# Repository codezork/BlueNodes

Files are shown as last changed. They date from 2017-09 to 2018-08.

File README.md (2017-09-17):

# BlueNodes
Bluetooth Smart Home Appliance

BlueNodes is a Smart Home system. Each BlueNode is a small box containing a Bluetooth Low Energy chip, a MOSFET switch, a current measurement sensor and a power supply. Together they establish a mesh-network of Bluetooth® devices and broadcast values to their neighbours. BlueNode devices are inserted in power supply lines to control and measure the power consumption of the endpoint. Android devices since version 4.4 with an installed BlueNodes Controller application are able to connect to the closest BlueNode and exchange information with any node in the network. Every node is reachable in the network as long as a broadcasting path exists to the addressed node. The number of nodes is nearly unlimited. A node can be mounted inside wall sockets, lamp stands, junction boxes and light switches. BlueNode devices can switch or dim loads while supplying continuous information about power consumption of each node in the network. You can start your Smart Home with just one BlueNode.

== Usage
The BlueNodes system consists of hardware, firmware and android software.

=== Prerequisites
==== Hardware
To read and modify schematics and pcb layout, you need to install gEDA (http://www.geda-project.org/) from: http://wiki.geda-project.org/geda:download. You have to copy the gEDA folder of this repo over your gEDA installation to add symbols and footprints that are added for this project. You have to add the bluenodes directory to the gEDA settings or copy footprints (*.fp) and symbols (*.sym) to an existing folder. Gerber files of the latest version and images of the pcb are included. The gerber files can directly be used to order a 4 layer pcb at a pcb manufacturer, e.g.: http://www.pcb-pool.com/.
==== Firmware
If you want to upload new versions of the firmware to the BlueNodes hardware, you either need to have a J-Link debug probe from https://www.segger.com/products/debug-probes/j-link/ or you buy a Nordic development board and solder your connection by yourself. The board and all the used chips and parts are available from Mouser Electronics http://www.mouser.de/.
To compile the firmware, use EmBitz version 1.11. You can download it here: https://www.embitz.org/.
==== Android
Get the latest version of Android Studio from https://developer.android.com/studio/index.html.
== License
Schematic and pcb layout, firmware and android software is published, as far as not under the Nordic Semiconductor ASA license (Nordic LICENSE file), under the Apache 2.0 license.

== Disclaimer
Although the author takes all possible care to ensure the correctness of published information, no warranty can be accepted regarding the correctness, accuracy, uptodateness, reliability and completeness of the content of this information. The author expressly reserves the right to change, to delete or temporarily not to publish the contents wholly or partly at any time and without giving notice. Liability claims against the author because of tangible or intangible damage arising from accessing, using or not using the published information, through misuse of the connection or as a result of technical breakdowns are excluded.

=== Warning
The hardware includes a so called "Buck Converter" which does not implement galvanic separation from the mains. Therefore care must be taken and the device should never be touched when connected to mains.
While high voltage systems can be dangerous, and if not treated with care, respect and intelligence, they can result in fatal injuring. Damaging effects which can be induced in the body by electric shock or contact with live electrical systems include:
1. Ventricular fibrillation - defined by the New Oxford American Dictionary as "(of a muscle, esp. in the heart) make a quivering movement due to uncoordinated contraction of the individual fibrils." This is a potentially fatal condition where the heart muscle quivers rather than beats, eliminating blood flow and causing death.
2. Cardiac asystole - where the heart stops beating. Combined with ventricular fibrillation this constitutes cardiac arrest.
3. Respiratory arrest.
4. Burns from arc flash and resistive heating of body tissues.
5. Radio frequency burns if radio or microwave frequencies are used.
If you are not familiar with devices connected to mains and voltages higher that 35 volts, contact a specialist before connecting a BlueNodes device to mains. The author cannot be held liabile for personal injuries or other damages resulting in the use of the published schematics.
Also, a Buck Converter can emit ERM which should always be shielded. The schamatics and the pcb layout takes care about this fact.

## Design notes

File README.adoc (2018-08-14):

= BlueNodes
Bluetooth Smart Home Appliance

BlueNodes is a Smart Home system. Each BlueNode is a small box containing a Bluetooth Low Energy chip, a MOSFET switch, a current measurement sensor and a power supply. Together they establish a mesh-network of Bluetooth® devices and broadcast values to their neighbours. BlueNode devices are inserted in power supply lines to control and measure the power consumption of the endpoint. Android devices since version 4.4 with an installed BlueNodes Controller application are able to connect to the closest BlueNode and exchange information with any node in the network. Every node is reachable in the network as long as a broadcasting path exists to the addressed node. The number of nodes is nearly unlimited. A node can be mounted inside wall sockets, lamp stands, junction boxes and light switches. BlueNode devices can switch or dim loads while supplying continuous information about power consumption of each node in the network. You can start your Smart Home with just one BlueNode.

== General
The BlueNodes system consists of hardware, firmware and android software. The firmware is based on https://github.com/NordicSemiconductor/nRF51-ble-bcast-mesh[nRF OpenMesh].
To understand the complete project read link:docs/details.adoc[Details].

== Prerequisites

=== Hardware
To read and modify schematics and pcb layout, you need to install gEDA (http://www.geda-project.org/) from: http://wiki.geda-project.org/geda:download. You have to copy the gEDA folder of this repo over your gEDA installation to add symbols and footprints that are needed for this project. You have to add the bluenodes directory to the gEDA settings or copy footprints and symbols to an existing gEDA symbol and footprint folder. 

Gerber files of the latest version and images of the pcb are in the repo. The pcb is assembled from both sides with SMD parts mounting form 0402. The gerber files can directly be used to order a 4 layer pcb at a pcb manufacturer, e.g.: http://www.pcb-pool.com/.

=== Firmware
If you want to upload new versions of the firmware to the BlueNodes hardware, you either need to have a J-Link debug probe from https://www.segger.com/products/debug-probes/j-link/ or you buy a Nordic development board and solder the connection yourself. See https://devzone.nordicsemi.com/question/80853/external-programming-using-nrf52-dk/. +
The development board and all parts needed for BlueNodes are available from Mouser Electronics http://www.mouser.de/. Order numbers for Mouser parts should be supplied in the schematics.

To compile the firmware, use EmBitz from version 1.11. You can download it here: https://www.embitz.org/.

=== Android
Get the latest version of Android Studio from https://developer.android.com/studio/index.html.

== License
Schematic and pcb layout, firmware and android software is published, as far as not under the Nordic Semiconductor ASA license (Nordic LICENSE file), under the *Apache 2.0 license*.

== Disclaimer
Although the author takes all possible care to ensure the correctness of published information, no warranty can be accepted regarding the correctness, accuracy, uptodateness, reliability and completeness of the content of this information. The author expressly reserves the right to change, to delete or temporarily not to publish the contents wholly or partly at any time and without giving notice. Liability claims against the author because of tangible or intangible damage arising from accessing, using or not using the published information, through misuse of the connection or as a result of technical breakdowns are excluded.

=== Warning!
The hardware includes a so called "Buck Converter" which does not implement galvanic separation from the mains. Therefore care must be taken and the device should never be touched when connected to mains.
While high voltage systems can be dangerous, and if not treated with care, respect and intelligence, they can result in fatal injuring. Damaging effects which can be induced in the body by electric shock or contact with live electrical systems include: +
1. Ventricular fibrillation - defined by the New Oxford American Dictionary as "(of a muscle, esp. in the heart) make a quivering movement due to uncoordinated contraction of the individual fibrils." This is a potentially fatal condition where the heart muscle quivers rather than beats, eliminating blood flow and causing death. +
2. Cardiac asystole - where the heart stops beating. Combined with ventricular fibrillation this constitutes cardiac arrest. +
3. Respiratory arrest. +
4. Burns from arc flash and resistive heating of body tissues. +
5. Radio frequency burns if radio or microwave frequencies are used. +
If you are not familiar with devices connected to mains and voltages higher that 35 volts, contact a specialist before connecting a BlueNodes device to mains. The author cannot be held liabile for personal injuries or other damages resulting in the use of the published schematics. +
Also, a Buck Converter can emit ERM which should always be shielded. The schematics and the pcb layout takes care about this fact.

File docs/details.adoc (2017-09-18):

== Features

*Simplicity*
BlueNodes are easy to install at any place in the electrical circuit of a facility. They work with every AC mains voltage from 85V up to 265V. No extra power supply is needed for the devices.

*Extensibility*
installations can easily be extended starting with a single node because new nodes integrate seamlessly into the network without programming an address. 

*Independence*
any Android driven device with Bluetooth® 4.0 capabilities can hook into the network and control loads or gain live data over power consumptions. No special hardware is required. 

*Maintainability and Sustainability*
when firmware updates become available OTA-DFU (Over the Air Device Firmware Update) transports new firmware from the Android device to all nodes.

*Security*
Nodes can detect short-circuit situations or overload and cut mains before any fuse can break. An in-built temperature sensor avoids overheating. 

*Convenience*
Android devices with a running BlueNodes Controller application, automatically log into the mesh-network as they come into range. 

== Software
=== Firmware
uses BLE protocol stack, rebroadcasting mesh network technology using the IETF RFC6206 Trickle algorithm. Each node has a unique address and embedds automatically into an existing network. Different channels and access addresses can be configured to separate networks. Electrical current is measured by the sensor and converted continuously by the A/D converter.

=== Android Software
the Java based Android software automatically connects to the closest BlueNode. Once connected, all nodes are reachable. The facility can be structured in buildings - floors - rooms - lamps or other loads. New nodes can be inserted and given a name and icon. Structural data is stored in the Android devices' Sqlite database. The power management displays accumulated consumption statistics in kWh per Minute of an hour - hour of a day - day of a month - etc. The values are permanently stored in the devices' flash memory and can be reset anytime.

== Hardware
*PCB*
assembled double side on a 4 layer PCB 37.5 x 27 mm using SMD 0402 parts.

*SOC*
NRF51x22 based on ARM® Cortex M0 32 bit processor 16 MHz clock Bluetooth® 4.0 low energy 2.4 GHz RF.

*RF*
Johanson Technology 2.4 GHz SMD ceramic antenna with impedance matched balun and band pass filter.

*Current Sensor*
Infineon TLI4970-D025T5 miniature coreless magnetic current sensor for AC and DC measurements with digital interface and fast overcurrent detection.

*Load Switch*
dual Infineon MOSFET 600V CoolMOS™ CE Power Transistor with trailing-edge phase cut control.

*Power Supply*
VIPer™06 30 kHz PWM non-isolated buck converter circuit with 1.8V and 5V LDO output. Maximum   power consumption 30mA during continuous RF communication.

*Indicators*
2 LED indicating connection and health status.

*Interface*
5 pin connector pad with Vdd, GND, GND detect, SWDIO and SWDCLK

Block diagram

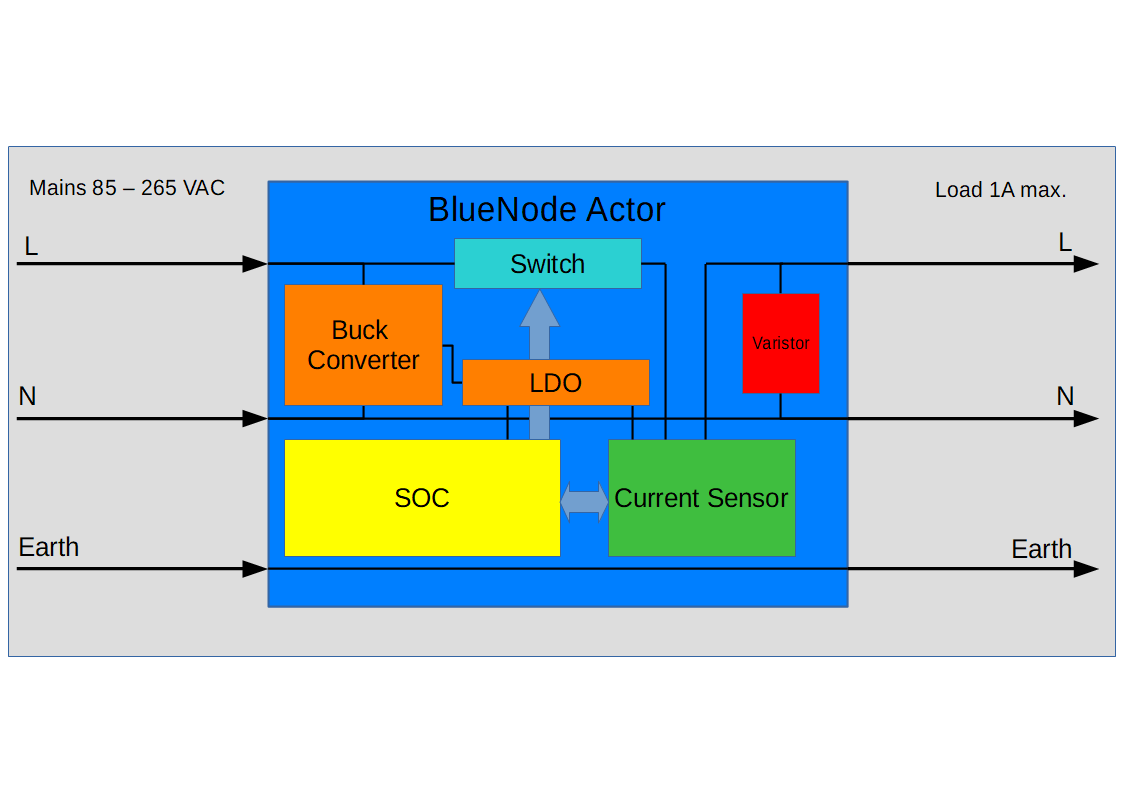
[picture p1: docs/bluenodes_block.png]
Block diagram


Schematics

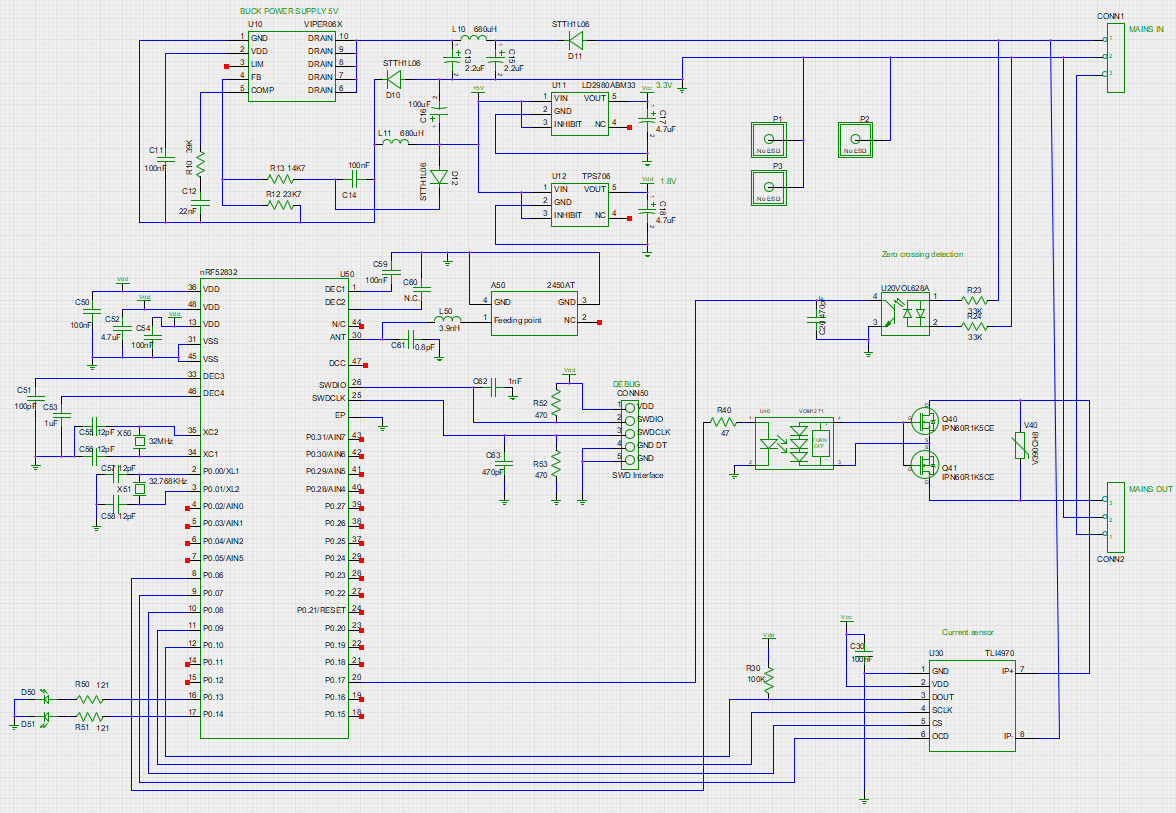
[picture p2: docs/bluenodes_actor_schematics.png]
Schematics


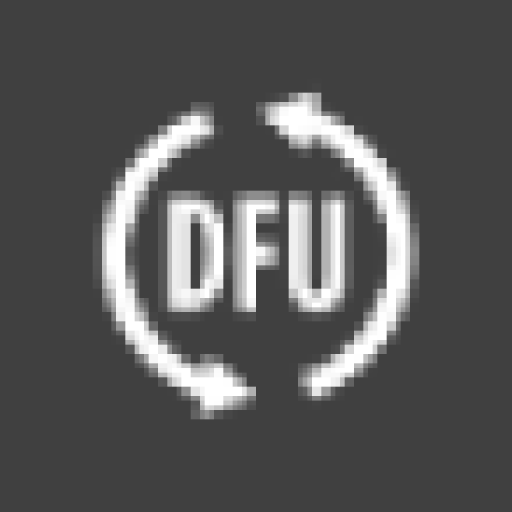
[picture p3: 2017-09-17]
mobile/bluenodes/src/main/ic_stat_notify_dfu-web.png

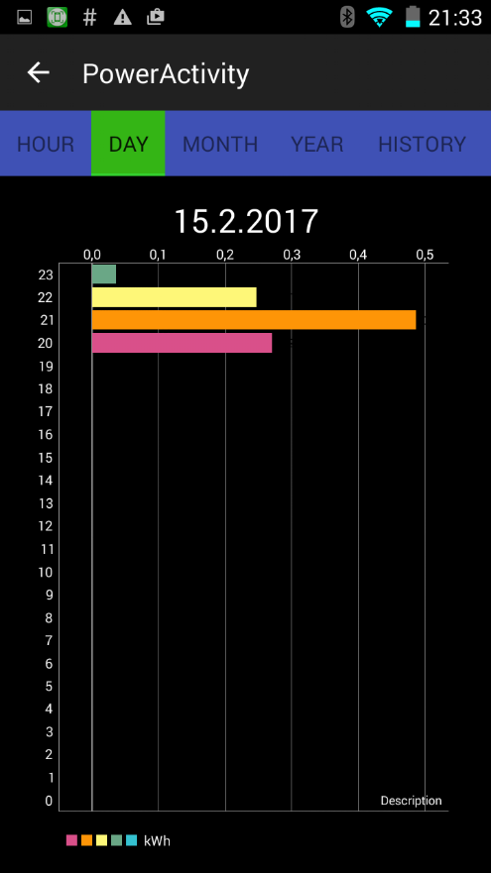
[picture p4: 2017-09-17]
screenshots/Screenshot_2017-02-15-21-33-17.png

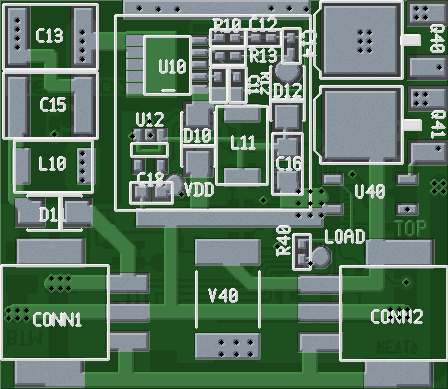
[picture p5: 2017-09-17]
pcb/bluenodes_actor52832-19-top.png

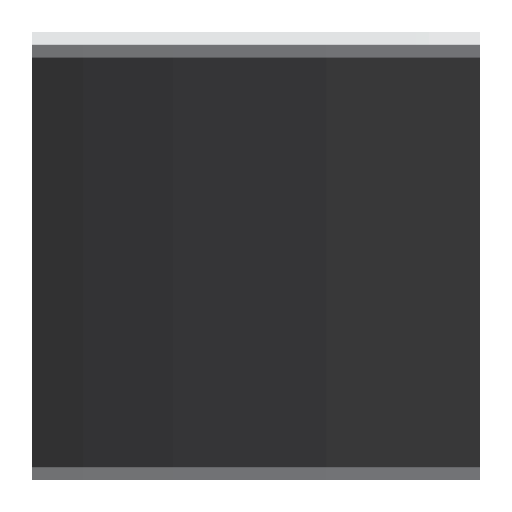
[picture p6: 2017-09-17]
mobile/bluenodes/src/main/battery-web.png

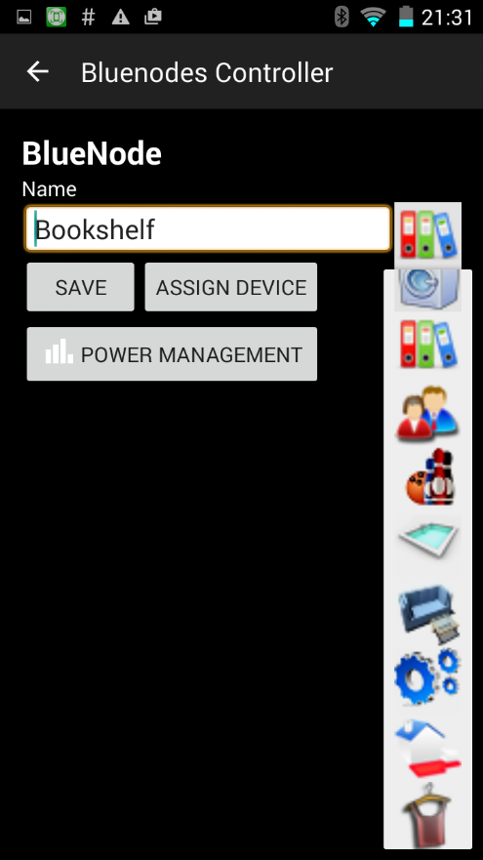
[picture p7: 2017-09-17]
screenshots/Screenshot_2017-02-15-21-31-52.png

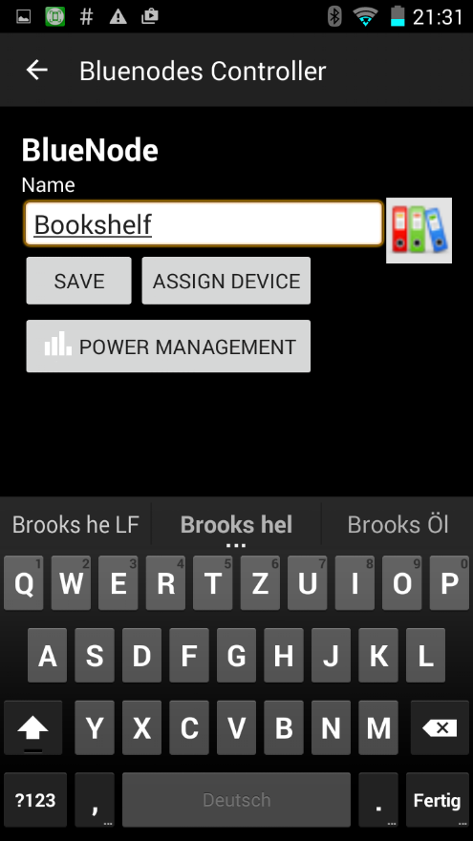
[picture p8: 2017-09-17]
screenshots/Screenshot_2017-02-15-21-31-35.png

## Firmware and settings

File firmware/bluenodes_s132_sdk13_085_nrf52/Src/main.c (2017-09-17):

/***********************************************************************************
Copyright (c) Bluenodes GmbH
All rights reserved.

Redistribution and use in source and binary forms, with or without modification,
are not permitted.
************************************************************************************/

#include "rbc_mesh.h"
#include "nrf_adv_conn.h"
#include "nrf_soc.h"
#include "softdevice_handler.h"
#include "nrf_drv_rng.h"
#include <string.h>
#include "app_button.h"
#include "app_timer.h"
#include "bas_adc.h"
#include "fstorage.h"
#include "fstorage_internal_defs.h"
#include "led_config.h"
#include "mesh.h"
#include "config.h"
#include "common.h"
#include "peripheral.h"
#include "current_cube.h"
#ifdef MESH_DFU
#include "dfu_app.h"
#endif

#include "SEGGER_RTT.h"

/** rtc timers **/
// request addresses timeout
#define REQUEST_DEVICEADDRESSES_TIMEOUT					APP_TIMER_TICKS(10)
APP_TIMER_DEF(m_request_deviceaddress_timer_id);
#define TEMPERATURE_TIMEOUT					            APP_TIMER_TICKS(1000)
APP_TIMER_DEF(m_temperature_timer_id);
// notify error timeout
APP_TIMER_DEF(m_notify_error_timer_id);

// message to host service timeout
APP_TIMER_DEF(m_message_timer_id);

/** global variables **/
static mesh_value_t                     m_message;
static volatile bool                    m_radio_active = false;
static volatile bool                    m_connected = false;
static volatile bool                    m_memory_access_in_progress = false;
// global static device adress
static ble_gap_addr_t 					m_my_addr;

/**
* @brief General error handler.
*/
static void error_loop(void) {
	while (true) {
		__WFE();
	}
}

/**@brief Callback function for asserts in the SoftDevice.
 *
 * @details This function will be called in case of an assert in the SoftDevice.
 *
 * @warning This handler is an example only and does not fit a final product. You need to analyze
 *          how your product is supposed to react in case of Assert.
 * @warning On assert from the SoftDevice, the system can only recover on reset.
 *
 * @param[in] line_num   Line number of the failing ASSERT call.
 * @param[in] file_name  File name of the failing ASSERT call.
 */
void assert_nrf_callback(uint16_t line_num, const uint8_t * p_file_name)
{
    app_error_handler(DEAD_BEEF, line_num, p_file_name);
}

void app_error_fault_handler(uint32_t id, uint32_t pc, uint32_t info) {
#ifndef DEBUG
    NVIC_SystemReset();
#else
    SEGGER_RTT_printf(0, "app_error_print():\r\n");
    SEGGER_RTT_printf(0, "Fault identifier:  0x%X\r\n", id);
    SEGGER_RTT_printf(0, "Program counter:   0x%X\r\n", pc);
    SEGGER_RTT_printf(0, "Fault information: 0x%X\r\n", info);

#ifndef DEBUG
    if(info == 0) {
        SEGGER_RTT_printf(0, "reset due to sd assert\r\n");
        NVIC_SystemReset();
    }
#endif
    switch (id)
    {
        case NRF_FAULT_ID_SDK_ASSERT:
            SEGGER_RTT_printf(0, "Line Number: %u\r\n", ((assert_info_t *)(info))->line_num);
            SEGGER_RTT_printf(0, "File Name:   %s\r\n", ((assert_info_t *)(info))->p_file_name);
            break;

        case NRF_FAULT_ID_SDK_ERROR:
            SEGGER_RTT_printf(0, "Line Number: %u\r\n",   ((error_info_t *)(info))->line_num);
            SEGGER_RTT_printf(0, "File Name:   %s\r\n",   ((error_info_t *)(info))->p_file_name);
            SEGGER_RTT_printf(0, "Error Code:  0x%X\r\n", ((error_info_t *)(info))->err_code);
            break;
    }
#endif
}

/**
* @brief Softdevice crash handler, never returns
*
* @param[in] pc Program counter at which the assert failed
* @param[in] line_num Line where the error check failed
* @param[in] p_file_name File where the error check failed
*/
void sd_assert_handler(uint32_t pc, uint16_t line_num, const uint8_t* p_file_name) {
    SEGGER_RTT_printf(0, "sd_error_print():\r\n");
    SEGGER_RTT_printf(0, "Program counter:   0x%X\r\n", pc);
    SEGGER_RTT_printf(0, "Line Number: %u\r\n", line_num);
    SEGGER_RTT_printf(0, "File Name:   %s\r\n", p_file_name);
	error_loop();
}

void HardFault_Handler(void) {
	error_loop();
}

void ble_radio_notification_evt_handler(bool radio_active) {
    m_radio_active = radio_active;
}

void ble_connect_event_handler(bool connected) {
    m_connected = connected;
    led_config(1,connected);
    if(connected) {
        SEGGER_RTT_printf(0, "CONNECTED\n");
    } else {
        SEGGER_RTT_printf(0, "DISCONNECTED\n");
    }
}

void adc_value_notification_evt_handler(float value, bool isMinute) {
    app_timer_stop(m_message_timer_id);
    float pwr = calc_watt_hour(value);
    pwr = value;
#ifdef SHOW_POWER
    if(m_connected) {
        memcpy((uint8_t*)m_message.value, (uint8_t*)&pwr, sizeof(float));
        m_message.size = sizeof(float);
        m_message.handle = MESSAGE_CHARACTERISTIC_HANDLE;
        app_timer_start(m_message_timer_id, NOTIFICATION_TIMEOUT, &m_message);
    }
#endif
    if(isMinute) {
        cube_set_power(pwr);
    }
}

/**
* @brief Softdevice event handler
*/
void sd_ble_evt_handler(ble_evt_t* p_ble_evt)
{
    rbc_mesh_ble_evt_handler(p_ble_evt);
    nrf_adv_conn_evt_handler(p_ble_evt);
#ifdef BATTERY_SERVICE
    bas_adc_on_ble_evt(p_ble_evt);
#endif
}

/**@brief Function for handling the Application's system events.
 *
 * @param[in]   sys_evt   system event.
 */
static void on_sys_evt(uint32_t sys_evt)
{
    switch (sys_evt)
    {
        case NRF_EVT_FLASH_OPERATION_SUCCESS:
        /* fall through */
        case NRF_EVT_FLASH_OPERATION_ERROR:

            if (m_memory_access_in_progress)
            {
                m_memory_access_in_progress = false;
            }
            break; // NRF_EVT_FLASH_OPERATION_SUCCESS and NRF_EVT_FLASH_OPERATION_ERROR
        default:
            // No implementation needed.
            break;
    }
}

/**@brief Function for dispatching a system event to interested modules.
 *
 * @details This function is called from the System event interrupt handler after a system
 *          event has been received.
 *
 * @param[in]   sys_evt   System stack event.
 */
static void sys_evt_dispatch(uint32_t sys_evt)
{
    rbc_mesh_sd_evt_handler(sys_evt);
    fs_sys_event_handler(sys_evt);
    on_sys_evt(sys_evt);
}

void print_data(char *type, uint8_t *address, uint8_t len)
{
#ifdef VERBOSE
    SEGGER_RTT_printf(0, "%s ", type);
    for(char i=0; i<len; i++)
        SEGGER_RTT_printf(0, "%02x", *(address+i));
    SEGGER_RTT_printf(0, "\n");
#endif
}

void send_mesh_value(uint8_t characteristic, uint8_t *in, uint8_t size, bool with_address) {
	uint32_t err_code;
	uint8_t tx_buffer[RBC_MESH_VALUE_MAX_LEN];
	memset(tx_buffer, 0, RBC_MESH_VALUE_MAX_LEN);
	uint8_t *ptr = tx_buffer;
	uint8_t max_size = RBC_MESH_VALUE_MAX_LEN;
	if(with_address) {
		memcpy(ptr, (uint8_t*)m_my_addr.addr, BLE_GAP_ADDR_LEN);
		ptr += BLE_GAP_ADDR_LEN;
		max_size -= BLE_GAP_ADDR_LEN;
	}
	if(max_size < size) {
		size = max_size;
	}
	memcpy(ptr, in, size);
	uint8_t length = with_address?BLE_GAP_ADDR_LEN+size:size;
	err_code = rbc_mesh_value_set(characteristic, tx_buffer, length);
	if (err_code != NRF_SUCCESS &&
			err_code != BLE_ERROR_INVALID_CONN_HANDLE &&
			err_code != NRF_ERROR_INVALID_STATE) {
		APP_ERROR_CHECK(err_code);
	}
}

void request_deviceaddresses_timeout_handler(void * p_context) {
	uint32_t err_code;

	app_timer_stop(m_request_deviceaddress_timer_id);
#ifdef VERBOSE
	print_data("answer address", m_my_addr.addr, BLE_GAP_ADDR_LEN);
#endif
	err_code = rbc_mesh_value_set(ANSWER_DEVICEADDRESS_CHARACTERISTIC_HANDLE, (void*)m_my_addr.addr, BLE_GAP_ADDR_LEN);
	if (err_code != NRF_SUCCESS &&
			err_code != BLE_ERROR_INVALID_CONN_HANDLE &&
			err_code != NRF_ERROR_INVALID_STATE) {
		APP_ERROR_CHECK(err_code);
	}
}

void message_timeout_handler(void * p_context) {
	mesh_value_t *val = p_context;
	send_mesh_value(val->handle, &val->value[0], val->size, true);
}

void message(mesh_value_t *message) {
	app_timer_stop(m_message_timer_id);
	memcpy(&m_message, message, sizeof(mesh_value_t));
	app_timer_start(m_message_timer_id, NOTIFICATION_TIMEOUT, &m_message);
}

void notify_error_timeout_handler(void * p_context)
{
	mesh_value_t *val = p_context;
	send_mesh_value(val->handle, &val->value[0], val->size, true);
}

void notify_error(mesh_value_t *message) {
	app_timer_stop(m_notify_error_timer_id);
	memcpy(&m_message, message, sizeof(mesh_value_t));
	app_timer_start(m_notify_error_timer_id, NOTIFICATION_TIMEOUT, &m_message);
}

void temperature_timeout_handler(void * p_context) {
#ifdef SHOW_TEMPERATURE
    int32_t temp;
    if(m_connected && sd_temp_get(&temp) == NRF_SUCCESS) {
        float value = ((float)temp/4);
        send_mesh_value(MESSAGE_CHARACTERISTIC_HANDLE, (uint8_t*)&value, sizeof(float), true);
    }
#endif
}

/**
* @brief RBC_MESH framework event handler. Defined in rbc_mesh.h. Handles
*   events coming from the mesh.
*
* @param[in] evt RBC event propagated from framework
*/
void rbc_mesh_event_handler(rbc_mesh_event_t* evt) {
	uint8_t brightness;
#ifdef CUBE_STORAGE
	storage_event_handler(evt);
#endif
	switch (evt->type) {
	case RBC_MESH_EVENT_TYPE_TX:
		break;
	case RBC_MESH_EVENT_TYPE_CONFLICTING_VAL:
	case RBC_MESH_EVENT_TYPE_NEW_VAL:
	case RBC_MESH_EVENT_TYPE_UPDATE_VAL:
		switch (evt->params.rx.value_handle) {
		case BRIGHTNESS_CHARACTERISTIC_HANDLE:
			if(memcmp(evt->params.rx.p_data, m_my_addr.addr, BLE_GAP_ADDR_LEN) == 0) {
				memcpy(&brightness, evt->params.rx.p_data+BLE_GAP_ADDR_LEN, sizeof(brightness));
				set_brightness_soft(brightness);
			}
			break;
		case REQUEST_DEVICEADDRESS_CHARACTERISTIC_HANDLE:
#ifdef VERBOSE
			SEGGER_RTT_printf(0, "request device addresses type:%d\n", evt->type);
#endif
			app_timer_stop(m_request_deviceaddress_timer_id);
			uint8_t rnd_delay;
			nrf_drv_rng_rand(&rnd_delay, 1);
			app_timer_start(m_request_deviceaddress_timer_id, rnd_delay*REQUEST_DEVICEADDRESSES_TIMEOUT, NULL);
			break;
		case REQUEST_BRIGHTNESS_CHARACTERISTIC_HANDLE:
			if(memcmp(evt->params.rx.p_data, m_my_addr.addr, BLE_GAP_ADDR_LEN) == 0) {
#ifdef VERBOSE
				print_data("request brightness for", evt->params.rx.p_data, BLE_GAP_ADDR_LEN);
#endif
				request_brightness();
			}
			break;
		default:
			break;
		}
		break;
	case RBC_MESH_EVENT_TYPE_INITIALIZED:
//		/* init BLE gateway softdevice application: */
//		nrf_adv_conn_init();
        break;
#ifdef MESH_DFU
    case RBC_MESH_EVENT_TYPE_DFU_BANK_AVAILABLE:
        dfu_bank_flash(evt->params.dfu.bank.dfu_type);
        break;

    case RBC_MESH_EVENT_TYPE_DFU_NEW_FW_AVAILABLE:
        dfu_request(evt->params.dfu.new_fw.dfu_type,
            &evt->params.dfu.new_fw.new_fwid,
            (uint32_t*) 0x24000);
        break;

    case RBC_MESH_EVENT_TYPE_DFU_RELAY_REQ:
        dfu_relay(evt->params.dfu.relay_req.dfu_type,
            &evt->params.dfu.relay_req.fwid);
        break;

    case RBC_MESH_EVENT_TYPE_DFU_START:
    case RBC_MESH_EVENT_TYPE_DFU_END:
        break;
    case RBC_MESH_EVENT_TYPE_DFU_SOURCE_REQ:
        break;
#endif
	}
}

/**@brief Function for the Timer initialization.
 *
 * @details Initializes the timer module.
 */
static void timers_init(void)
{
    // Initialize timer module, making it use the scheduler
    app_timer_init();

    // create request addresses timer
    APP_ERROR_CHECK(app_timer_create(&m_request_deviceaddress_timer_id,
                                APP_TIMER_MODE_SINGLE_SHOT,
                                request_deviceaddresses_timeout_handler));
    // create message timer
    APP_ERROR_CHECK(app_timer_create(&m_message_timer_id,
                                APP_TIMER_MODE_SINGLE_SHOT,
                                message_timeout_handler));
    // create notify error timer
    APP_ERROR_CHECK(app_timer_create(&m_notify_error_timer_id,
                                APP_TIMER_MODE_SINGLE_SHOT,
                                notify_error_timeout_handler));
    // create temperature timer
    APP_ERROR_CHECK(app_timer_create(&m_temperature_timer_id,
                                APP_TIMER_MODE_REPEATED,
                                temperature_timeout_handler));
}

#ifdef BOARD_PCA10028
static void button_event_handler(uint8_t pin_no, uint8_t button_action)
{
    static uint8_t button_state = 0;
    if(button_action)
    {
        button_state |= (1<<(pin_no-17));
    }
    else
    {
        button_state &= ~(1<<(pin_no-17));
    }
#ifdef VERBOSE
    SEGGER_RTT_printf(0, "BUTTON %d state %d\n",pin_no, button_state );
#endif
	send_mesh_value(BUTTON_CHARACTERISTIC_HANDLE, &button_state, sizeof(button_state), true);
}
#endif

/**@brief Function for initializing the button handler module.
 */
static void buttons_init(void)
{
    // Note: Array must be static because a pointer to it will be saved in the Button handler
    //       module.file
#ifdef BOARD_PCA10028
    uint32_t err_code;
    static app_button_cfg_t buttons[] =
    {
        {BSP_BUTTON_0, false, BUTTON_PULL, button_event_handler},
        {BSP_BUTTON_1, false, BUTTON_PULL, button_event_handler},
        {BSP_BUTTON_2, false, BUTTON_PULL, button_event_handler},
        {BSP_BUTTON_3, false, BUTTON_PULL, button_event_handler}
    };
    err_code = app_button_init(buttons, sizeof(buttons) / sizeof(buttons[0]), BUTTON_DETECTION_DELAY);
    APP_ERROR_CHECK(err_code);
#endif
}

/** @brief main function */
int main(void)
{
#ifdef VERBOSE
#ifdef BOARD_PCA10028
    SEGGER_RTT_WriteString(0, "board 10028\n");
#endif
#ifdef BOARD_PCA10031
    SEGGER_RTT_WriteString(0, "board 10031\n");
#endif
#ifdef BOARD_BLUENODES
    SEGGER_RTT_WriteString(0, "board bluenodes\n");
#endif
#endif
    /* Enable Softdevice (including sd_ble before framework) */
	nrf_clock_lf_cfg_t clock_lf_cfg = MESH_CLOCK_SOURCE;
	// Initialize the SoftDevice handler module.
	SOFTDEVICE_HANDLER_INIT(&clock_lf_cfg, NULL);
    softdevice_ble_evt_handler_set(sd_ble_evt_handler);
	softdevice_sys_evt_handler_set(sys_evt_dispatch);

	gpio_init();
    timers_init();
    buttons_init();
	APP_ERROR_CHECK(peripheral_init(adc_value_notification_evt_handler));
//    scheduler_init();
    nrf_drv_rng_init(NULL);
#ifndef NO_BLE
    /* Init the rbc_mesh */
    rbc_mesh_init_params_t init_params;

    init_params.access_addr         = MESH_ACCESS_ADDR;
    init_params.interval_min_ms     = MESH_INTERVAL_MIN_MS;
    init_params.channel             = MESH_CHANNEL;
	init_params.lfclksrc            = clock_lf_cfg;
	init_params.tx_power            = RBC_MESH_TXPOWER_0dBm;

	APP_ERROR_CHECK(rbc_mesh_init(init_params));
#endif
    sd_ble_gap_addr_get(&m_my_addr);

#ifndef NO_BLE
	APP_ERROR_CHECK(rbc_mesh_value_enable(BRIGHTNESS_CHARACTERISTIC_HANDLE));
	APP_ERROR_CHECK(rbc_mesh_value_enable(BUTTON_CHARACTERISTIC_HANDLE));
	APP_ERROR_CHECK(rbc_mesh_value_enable(REQUEST_BRIGHTNESS_CHARACTERISTIC_HANDLE));
	APP_ERROR_CHECK(rbc_mesh_value_enable(REQUEST_DEVICEADDRESS_CHARACTERISTIC_HANDLE));
	APP_ERROR_CHECK(rbc_mesh_value_enable(ANSWER_BRIGHTNESS_CHARACTERISTIC_HANDLE));
	APP_ERROR_CHECK(rbc_mesh_value_enable(ANSWER_DEVICEADDRESS_CHARACTERISTIC_HANDLE));
	APP_ERROR_CHECK(rbc_mesh_value_enable(NOTIFY_DEVICE_ERROR_CHARACTERISTIC_HANDLE));
	APP_ERROR_CHECK(rbc_mesh_value_enable(SET_TIME_CHARACTERISTIC_HANDLE));
	APP_ERROR_CHECK(rbc_mesh_value_enable(CLEAR_STORAGE_CHARACTERISTIC_HANDLE));
	APP_ERROR_CHECK(rbc_mesh_value_enable(REQUEST_STORAGE_CHARACTERISTIC_HANDLE));
	APP_ERROR_CHECK(rbc_mesh_value_enable(ANSWER_STORAGE_CHARACTERISTIC_HANDLE));
	APP_ERROR_CHECK(rbc_mesh_value_enable(MESSAGE_CHARACTERISTIC_HANDLE));
#endif

#ifdef BOARD_PCA10028
    APP_ERROR_CHECK(app_button_enable());
#endif
#ifdef CUBE_STORAGE
    APP_ERROR_CHECK(cube_init(&m_my_addr));
#endif

#ifndef NO_BLE
	/* init BLE gateway softdevice application: */
	nrf_adv_conn_init(NODE_NAME, ble_connect_event_handler);
#ifdef BATTERY_SERVICE
    bas_init();
#endif
#ifdef SHOW_TEMPERATURE
    app_timer_start(m_temperature_timer_id, TEMPERATURE_TIMEOUT, NULL);
#endif
#endif
#ifdef VERBOSE
	SEGGER_RTT_WriteString(0, "init done\n");
#endif
	led_test();
	load_test();

    rbc_mesh_event_t evt;
    /* sleep */
    while (true)
    {
        sd_app_evt_wait();
#ifndef TEST_DEBUG
		if (rbc_mesh_event_get(&evt) == NRF_SUCCESS) {
			rbc_mesh_event_handler(&evt);
			rbc_mesh_event_release(&evt);
		}
#endif
#ifdef CUBE_STORAGE
        cube_store();
#endif
    }
}

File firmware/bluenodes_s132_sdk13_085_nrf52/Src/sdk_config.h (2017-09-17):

/**
 * Copyright (c) 2017 - 2017, Nordic Semiconductor ASA
 *
 * All rights reserved.
 *
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
 * 3. Neither the name of Nordic Semiconductor ASA nor the names of its
 *    contributors may be used to endorse or promote products derived from this
 *    software without specific prior written permission.
 *
 * 4. This software, with or without modification, must only be used with a
 *    Nordic Semiconductor ASA integrated circuit.
 *
 * 5. Any software provided in binary form under this license must not be reverse
 *    engineered, decompiled, modified and/or disassembled.
 *
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
 */

#ifndef SDK_CONFIG_H
#define SDK_CONFIG_H
// <<< Use Configuration Wizard in Context Menu >>>\n
#ifdef USE_APP_CONFIG
#include "app_config.h"
#endif

// <h> nRF_ANT
//==========================================================
// <e> ANTFS_ENABLED - ant_fs - ANT File Share module.
//==========================================================
#ifndef ANTFS_ENABLED
#define ANTFS_ENABLED 0
#endif
#if  ANTFS_ENABLED
// <o> ANTFS_CONFIG_NETWORK_NUMBER - ANT-FS network number.
#ifndef ANTFS_CONFIG_NETWORK_NUMBER
#define ANTFS_CONFIG_NETWORK_NUMBER 0
#endif

// <o> ANTFS_CONFIG_CHANNEL_NUMBER - ANT-FS channel number.
#ifndef ANTFS_CONFIG_CHANNEL_NUMBER
#define ANTFS_CONFIG_CHANNEL_NUMBER 0
#endif

// <o> ANTFS_CONFIG_PAIRING_TIMEOUT - Pairing timeout - how long the UI will wait for a response to a pairing request before switching to the link layer, in seconds.
#ifndef ANTFS_CONFIG_PAIRING_TIMEOUT
#define ANTFS_CONFIG_PAIRING_TIMEOUT 120
#endif

// <o> ANTFS_CONFIG_LINK_COMMAND_TIMEOUT - Command timeout - how long the client will wait without receiving any commands before switching to the link layer, in seconds.
#ifndef ANTFS_CONFIG_LINK_COMMAND_TIMEOUT
#define ANTFS_CONFIG_LINK_COMMAND_TIMEOUT 10
#endif

// <o> ANTFS_CONFIG_TRANS_TYPE - ANT-FS Transmission Type.
#ifndef ANTFS_CONFIG_TRANS_TYPE
#define ANTFS_CONFIG_TRANS_TYPE 10
#endif

// <o> ANTFS_CONFIG_DEVICE_TYPE - ANT device type for channel configuration.
#ifndef ANTFS_CONFIG_DEVICE_TYPE
#define ANTFS_CONFIG_DEVICE_TYPE 1
#endif

// <o> ANTFS_CONFIG_BEACON_STATUS_PERIOD  - ANT-FS Beacon Message Period.

// <0=> 0.5 Hz
// <1=> 1 Hz
// <2=> 2 Hz
// <3=> 4 Hz
// <4=> 8 Hz

#ifndef ANTFS_CONFIG_BEACON_STATUS_PERIOD
#define ANTFS_CONFIG_BEACON_STATUS_PERIOD 3
#endif

// <o> ANTFS_CONFIG_TRANSMIT_POWER  - ANT Transmit Power.

// <0=> Lowest ANT Tx power level setting. (-20dBm)
// <1=> ANT Tx power > Lvl 0. (-12dBm)
// <2=> ANT Tx power > Lvl 1. (-4dBm)
// <3=> ANT Tx power > Lvl 2. Default tx power level. (0dBm)
// <4=> ANT Tx power > Lvl 3. (+4dBm)
// <128=> Custom tx power selection

#ifndef ANTFS_CONFIG_TRANSMIT_POWER
#define ANTFS_CONFIG_TRANSMIT_POWER 3
#endif

// <o> ANTFS_CONFIG_CUSTOM_TRANSMIT_POWER - ANT Custom Transmit Power.
#ifndef ANTFS_CONFIG_CUSTOM_TRANSMIT_POWER
#define ANTFS_CONFIG_CUSTOM_TRANSMIT_POWER 0
#endif

// <q> ANTFS_CONFIG_AUTH_TYPE_PAIRING_ENABLED  - Use pairing and key exchange authentication.


#ifndef ANTFS_CONFIG_AUTH_TYPE_PAIRING_ENABLED
#define ANTFS_CONFIG_AUTH_TYPE_PAIRING_ENABLED 0
#endif

// <q> ANTFS_CONFIG_AUTH_TYPE_PASSKEY_ENABLED  - Use passkey authentication.


#ifndef ANTFS_CONFIG_AUTH_TYPE_PASSKEY_ENABLED
#define ANTFS_CONFIG_AUTH_TYPE_PASSKEY_ENABLED 0
#endif

// <q> ANTFS_CONFIG_AUTH_TYPE_PASSTHROUGH_ENABLED  - Allow host to bypass authentication.


#ifndef ANTFS_CONFIG_AUTH_TYPE_PASSTHROUGH_ENABLED
#define ANTFS_CONFIG_AUTH_TYPE_PASSTHROUGH_ENABLED 0
#endif

// <q> ANTFS_CONFIG_UPLOAD_ENABLED  - Support upload operation.


#ifndef ANTFS_CONFIG_UPLOAD_ENABLED
#define ANTFS_CONFIG_UPLOAD_ENABLED 0
#endif

// <q> ANTFS_CONFIG_DEBUG_LED_ENABLED  - Enables LED debug in the module.


#ifndef ANTFS_CONFIG_DEBUG_LED_ENABLED
#define ANTFS_CONFIG_DEBUG_LED_ENABLED 0
#endif

#endif //ANTFS_ENABLED
// </e>

// <e> ANT_BPWR_ENABLED - ant_bpwr - Bicycle Power Profile
//==========================================================
#ifndef ANT_BPWR_ENABLED
#define ANT_BPWR_ENABLED 0
#endif
#if  ANT_BPWR_ENABLED
// <e> ANT_BPWR_LOG_ENABLED - Enables general logging in the module.
//==========================================================
#ifndef ANT_BPWR_LOG_ENABLED
#define ANT_BPWR_LOG_ENABLED 0
#endif
#if  ANT_BPWR_LOG_ENABLED
// <o> ANT_BPWR_LOG_LEVEL  - Default Severity level

// <0=> Off
// <1=> Error
// <2=> Warning
// <3=> Info
// <4=> Debug

#ifndef ANT_BPWR_LOG_LEVEL
#define ANT_BPWR_LOG_LEVEL 3
#endif

// <o> ANT_BPWR_INFO_COLOR  - ANSI escape code prefix.

// <0=> Default
// <1=> Black
// <2=> Red
// <3=> Green
// <4=> Yellow
// <5=> Blue
// <6=> Magenta
// <7=> Cyan
// <8=> White

#ifndef ANT_BPWR_INFO_COLOR
#define ANT_BPWR_INFO_COLOR 0
#endif

#endif //ANT_BPWR_LOG_ENABLED
// </e>
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

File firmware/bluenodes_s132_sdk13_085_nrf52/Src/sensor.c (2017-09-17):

/***********************************************************************************
Copyright (c) Bluenodes GmbH
All rights reserved.

Redistribution and use in source and binary forms, with or without modification,
are not permitted.
************************************************************************************/

#include "nrf_error.h"
#include "nrf_timer.h"
#include "nrf_drv_timer.h"
#include "nrf_drv_spi.h"
#include "nordic_common.h"
#include <stdbool.h>
#include <stdint.h>
#include <string.h>
#include <stdio.h>
#include <stdlib.h>
#include "rbc_mesh.h"
#include "app_util_platform.h"
#include "app_error.h"
#include "app_scheduler.h"
#include "app_gpiote.h"
#include "app_timer_appsh.h"
#include "sensor.h"
#include "peripheral.h"
#include "current_cube.h"
#include "mesh.h"
#include "common.h"
#include "led_config.h"
#include "boards.h"

#include "SEGGER_RTT.h"

#ifdef CURRENTSENSOR

#ifndef OCD
#define OCD  10
#endif

#define ZERO_BRIDGE 18

// spi master
#define SPI_INSTANCE                                    0
static const nrf_drv_spi_t 								m_spi = NRF_DRV_SPI_INSTANCE(SPI_INSTANCE);
static const nrf_drv_timer_t                            measurement_timer = NRF_DRV_TIMER_INSTANCE(2);

#define CURRENT_MEASUREMENT_INTERVAL					APP_TIMER_TICKS(500, APP_TIMER_PRESCALER)
APP_TIMER_DEF(m_measurement_timer_id);

static volatile bool spi_xfer_done = true;              /**< Flag used to indicate that SPI instance completed the transfer. */
static uint8_t *m_rx_buf;                               /**< RX buffer. */
static uint8_t *m_rx_ptr;

static bool								m_oc_detected = false;
static volatile bool                    m_radio_active = false;
static volatile float                   m_value = 0;
static volatile bool                    spi_transfer_done = true;
static volatile bool                    send_message_done = true;

static int m_counter = 0;

static mesh_value_t                     m_overcurrent = {
    .value[0] = 0, \
    .size = 1, \
    .handle = NOTIFY_DEVICE_ERROR_CHARACTERISTIC_HANDLE};

static mesh_value_t                     m_message = {
    .value[0] = 0, \
    .value[1] = 0, \
    .value[2] = 0, \
    .value[3] = 0, \
    .size = 4, \
    .handle = MESSAGE_CHARACTERISTIC_HANDLE};

void set_ocd()
{
    set_brightness(0);
    m_oc_detected = true;
}

void reset_ocd()
{
    m_oc_detected = false;
    reset_brightness();
}

void ocd_event_handler(nrf_drv_gpiote_pin_t pin, nrf_gpiote_polarity_t action)
{
    // over current was detected
    set_ocd();
    m_overcurrent.value[0] = CSERROR_OVERCURRENT;
    m_overcurrent.size = 1;
    m_overcurrent.handle = NOTIFY_DEVICE_ERROR_CHARACTERISTIC_HANDLE;
    notify_error(&m_overcurrent);
}

void overcurrent_init()
{
    // init the overcurrent interrupt
    nrf_drv_gpiote_in_config_t ocd_config = GPIOTE_CONFIG_IN_SENSE_LOTOHI(true);
    ocd_config.pull = NRF_GPIO_PIN_PULLUP;
    APP_ERROR_CHECK(nrf_drv_gpiote_in_init(OCD, &ocd_config, ocd_event_handler));
    nrf_drv_gpiote_in_event_enable(OCD, true);
}

void sensor_timeout_handler(void * p_context)
{
    if(spi_transfer_done) {
        send_message_done = false;
        send_mesh_value(m_message.handle, &m_message.value[0], sizeof(float), true);
        send_message_done = true;
    }
}

void trigger_event_handler(nrf_timer_event_t event_type, void* p_context)
{
    switch(event_type)
    {
        case NRF_TIMER_EVENT_COMPARE0:
            if(send_message_done) {
                do_measurement();
            }
            break;
        default:
            //Do nothing.
            break;
    }
}

void sensor_init()
{
#ifdef VERBOSE
    SEGGER_RTT_printf(0, "sensor init\n");
#endif
    uint32_t err;
    err = spi_init();
    if(err != NRF_SUCCESS) {
   		APP_ERROR_CHECK(err);
        return;
    }
    // create current sensor timer
    APP_ERROR_CHECK(app_timer_create(&m_measurement_timer_id,
                                APP_TIMER_MODE_REPEATED,
                                measurement_timeout_handler));
    // create current storage values
    APP_ERROR_CHECK(app_timer_create(&m_request_storage_timer_id,
                                APP_TIMER_MODE_REPEATED,
                                request_storage_timeout_handler));
	nrf_drv_timer_config_t timer_config;
	timer_config.frequency = NRF_TIMER_FREQ_1MHz;
	timer_config.bit_width = NRF_TIMER_BIT_WIDTH_16;
	timer_config.interrupt_priority = APP_IRQ_PRIORITY_LOW;
	timer_config.mode = NRF_TIMER_MODE_TIMER;
	timer_config.p_context = NULL;
	APP_ERROR_CHECK(nrf_drv_timer_init(&measurement_timer, &timer_config, trigger_event_handler));
    nrf_drv_timer_extended_compare(&measurement_timer, NRF_TIMER_CC_CHANNEL0, 500, NRF_TIMER_SHORT_COMPARE0_CLEAR_MASK, true);

    APP_ERROR_CHECK(cube_init(&must_store));
    APP_ERROR_CHECK(app_timer_start(m_measurement_timer_id, CURRENT_MEASUREMENT_INTERVAL, NULL));
    nrf_drv_timer_enable(&measurement_timer);
#ifdef VERBOSE
    SEGGER_RTT_printf(0, "sensor init done\n");
#endif
}

void do_measurement() {
    m_counter ++;
    if(m_counter % 100 == 0) {
        led_toggle(2);
    }
    spi_transfer_done = false;
    nrf_drv_spi_transfer(&m_spi, NULL, 0, (uint8_t*)m_rx_ptr, 2);
}

void spi_event_handler(nrf_drv_spi_evt_t * p_event)
{
    uint16_t value;
    float    power = 0;
    uint16_t error = 0;
    uint16_t measurements = 0;

    spi_transfer_done = true;
    m_rx_ptr += 2;
    if(m_rx_ptr - m_rx_buf > RX_BUFFER_LENGTH)
    {
        m_rx_ptr = m_rx_buf;
        power = 0;
        while(m_rx_ptr - m_rx_buf <= RX_BUFFER_LENGTH)
        {
            // convert big-endian to little-endian
            value = ((*m_rx_ptr)<<8) | (*(m_rx_ptr+1));
            if(decode_value(value))
            {
                power += (float)(abs((value & CURRENTSENSOR_VALUEMASK) - 4096));
                measurements ++;
            }
            else
            {
                error ++;
            }
            m_rx_ptr += 2;
        }
        // arithmetic middle
        if(measurements > 0) {
            power /= measurements;
        }
        power *= 230/160;

#ifdef TEST_ZERO
        power = 7.4;
#endif
//		cube_set_value(power);
        memcpy((uint8_t*)&m_value, (uint8_t*)&power, sizeof(float));
        memset((uint8_t*)m_rx_buf, 0, RX_BUFFER_LENGTH);
        m_rx_ptr = m_rx_buf;

        memcpy((uint8_t*)m_message.value, (uint8_t*)&m_value, sizeof(float));
    }
}
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

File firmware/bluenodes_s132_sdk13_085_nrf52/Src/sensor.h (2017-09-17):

/***********************************************************************************
Copyright (c) Bluenodes GmbH
All rights reserved.

Redistribution and use in source and binary forms, with or without modification,
are not permitted.
************************************************************************************/

#ifndef SENSOR_H__
#define SENSOR_H__
#ifdef CURRENTSENSOR
#include "nrf_drv_gpiote.h"
#include "nrf_drv_spi.h"
#include "nrf_timer.h"
#include "rbc_mesh.h"
#include "config.h"

/** the pins **/
#define OCD_PIN  7            // over current signal.
#define SPIM0_SS_PIN    8     // SPI CSN signal.
#define SPIM0_SCK_PIN   9     // SPI SCK signal.
#define SPIM0_MISO_PIN  10    // SPI MISO signal.

/** current sensor message code to host **/
#define CSERROR_HARDWARE			1
#define CSERROR_OVERLOAD			2
#define CSERROR_OVERTEMP			4
#define CSERROR_COMMUNICATION		8
#define CSERROR_OVERCURRENT			16
/** current sensor chip codes **/
#define CURRENTSENSOR_VALUEMASK			0x1FFF
#define CURRENTSENSOR_STATUS			15
#define CURRENTSENSOR_PARITY			14
#define CURRENTSENSOR_OCDSTATE			13
#define CURRENTSENSOR_HARDWAREERROR		13
#define CURRENTSENSOR_OVERLOADERROR		12
#define CURRENTSENSOR_OVERTEMPERATURE	11
#define CURRENTSENSOR_COMMERROR			10

#define RX_BUFFER_LENGTH    200

void set_ocd();
void reset_ocd();
bool check_parity(uint16_t x);
void do_measurement();
void storage_event_handler(rbc_mesh_event_t* evt);
bool check_measurement(uint16_t value);
void sensor_init();
uint32_t spi_init();
void overcurrent_init();
void do_storage();
void sensor_event_handler(nrf_timer_event_t event_type, void* p_context);
#endif
#endif
